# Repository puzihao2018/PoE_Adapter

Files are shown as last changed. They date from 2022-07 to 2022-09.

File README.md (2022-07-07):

# PoE_Adapter

## The Idea

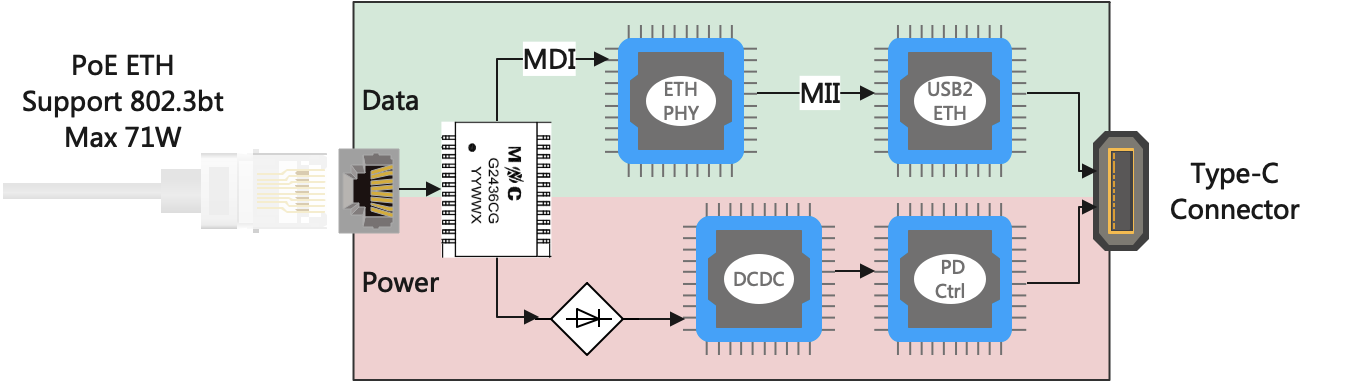
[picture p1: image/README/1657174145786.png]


## Requirements

* Support 802.3af, at, bt
* Maximum PoE input 71W
* Support 10M/100M/1G Ethernet, 2.5G or 10G better
* Support USB PD 60W(20V-3A) or higher, max to 65W
* Support USB PD 2.0 or higher, PPS support is better

## Related Knowledge

### About PoE

[什么是Power over Ethernet（PoE）? 它是如何工作的？ - 华为](https://info.support.huawei.com/info-finder/encyclopedia/zh/PoE.html)

[Power over Ethernet - Wikipedia](https://en.wikipedia.org/wiki/Power_over_Ethernet)

[](https://www.skyworksinc.com/-/media/Skyworks/SL/documents/public/white-papers/understanding-the-ieee-8023bt-poe-standard.pdf)

[【全系列】电源大咖课终极篇：EMC/功率隔离/PoE/LTspice_哔哩哔哩_bilibili](https://www.bilibili.com/video/BV1U54y167iA?p=6&vd_source=4a5614e8aaa017dad2b9a475db5972fe)

### About DCDC

### About USB2ETH

## Key Components

* [ ] 网口变压器
* [ ] PoE Interface IC
* [ ] ETH PHY Chip, MDI/MDIX to SGMII
* [ ] DCDC
* [ ] PD Control IC
* [ ] USB2ETH IC

## Possible Test Equipments

### PSE Devices

[HUAWEI ****AD-560161T0E POE++ Injector****](https://www.notion.so/HUAWEI-AD-560161T0E-POE-Injector-f2f963361bf641c6bf67e5bd52b6a7db)

[**Cudy POE400 90W Gigabit Ultra PoE++ Injector Adapter**](https://www.notion.so/Cudy-POE400-90W-Gigabit-Ultra-PoE-Injector-Adapter-ba70eb35d22a4e3bbaf1a9ec274cac1c)

[H3C S5130S-10MS-UPWR-EI Switch](https://www.notion.so/H3C-S5130S-10MS-UPWR-EI-Switch-632d7c23edca47faa28a7068c8aec5ac)

[QNAP ****QSW-M2116P-2T2S Switch****](https://www.notion.so/QNAP-QSW-M2116P-2T2S-Switch-efeddbc0777d48369dd353b2ddde7140)

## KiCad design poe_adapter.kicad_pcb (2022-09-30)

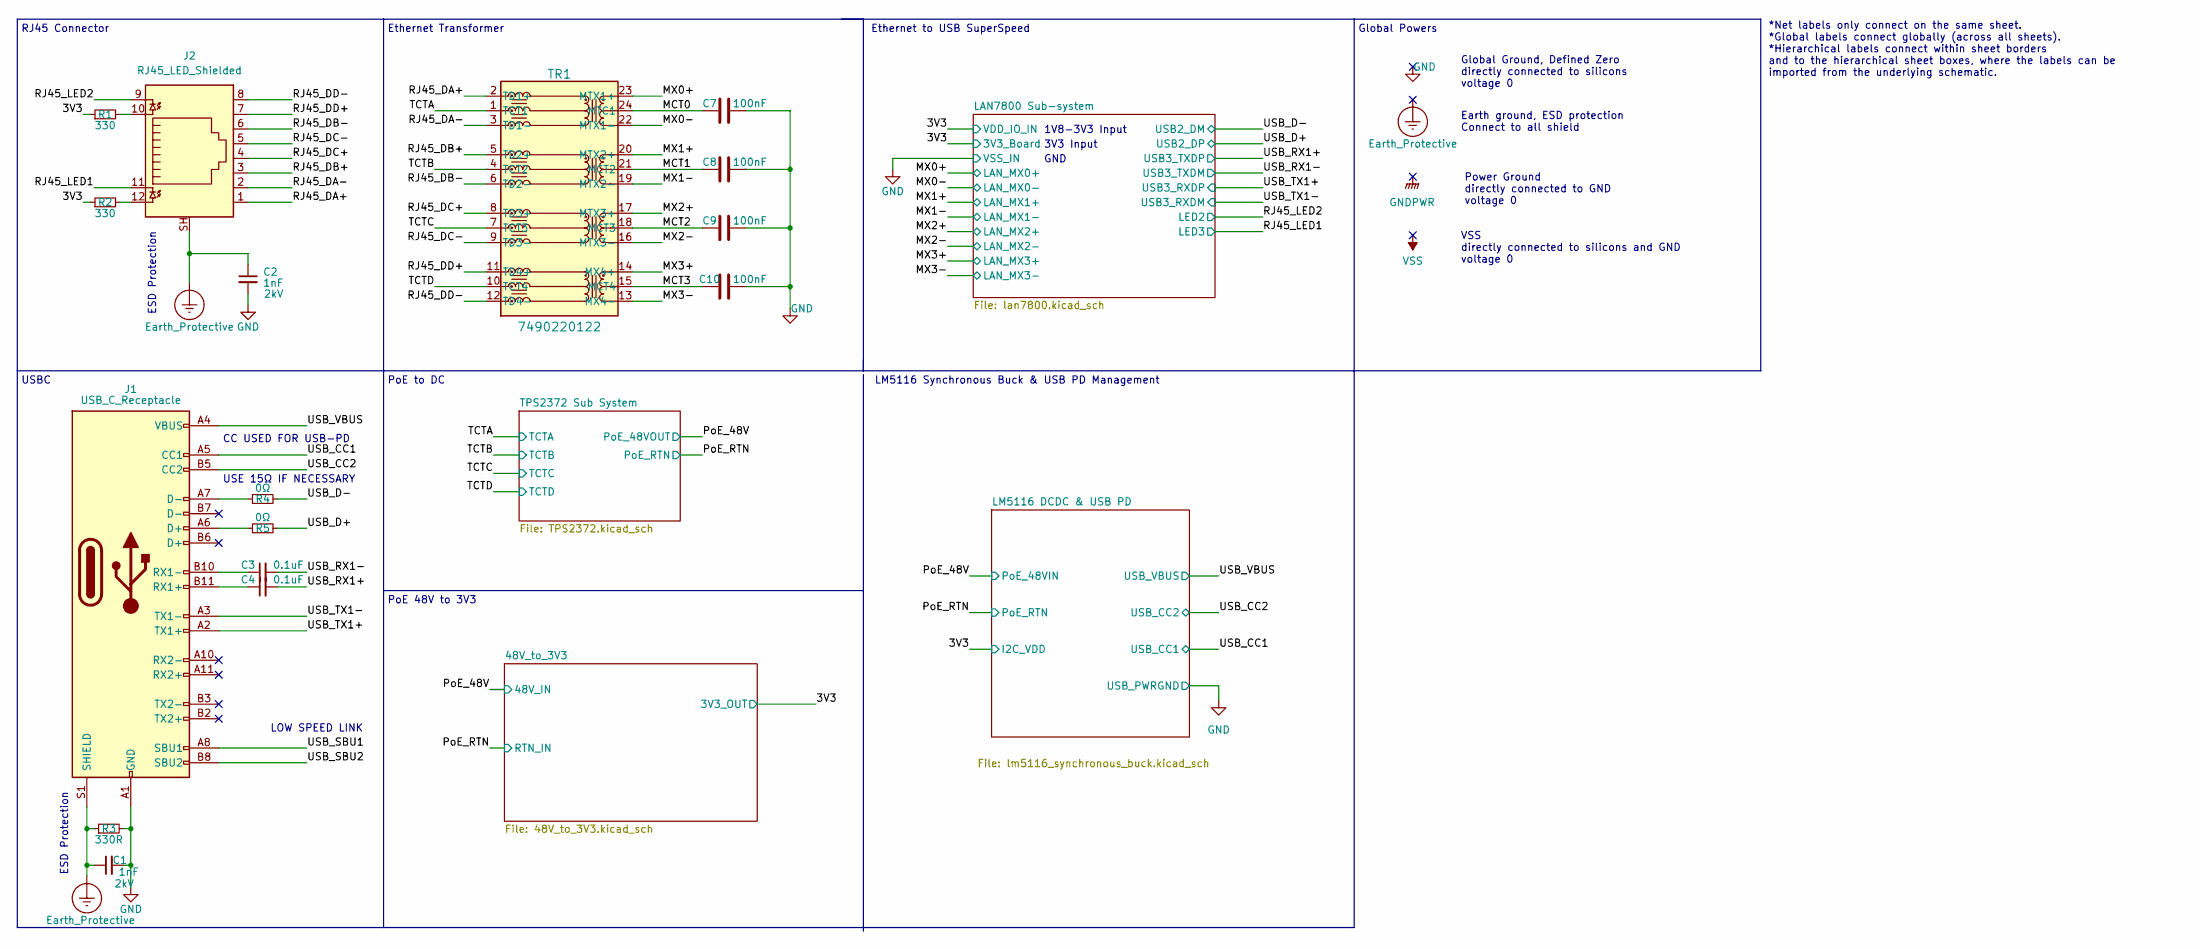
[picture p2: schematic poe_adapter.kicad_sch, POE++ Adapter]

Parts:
C1: 1nF; C_1206_3216Metric; Voltage 2kV
C2: 1nF; R_1206_3216Metric; Voltage 2kV
C3, C4: 0.1uF; C_0603_1608Metric
C7, C8, C9, C10: 100nF; C_1206_3216Metric
J1: USB_C_Receptacle; USB_C_Receptacle_Amphenol_12401610E4-2A_CircularHoles
J2: RJ45_LED_Shielded; RJ45_Amphenol_RJHSE538X
R1, R2: 330; R_0603_1608Metric
R3: 330R; R_0603_1608Metric
R4, R5: 0Ω; R_0603_1608Metric
TR1: 7490220122

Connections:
/MCT0: C7.2, TR1.24 (MTC1)
/MCT1: C8.2, TR1.21 (MCT2)
/MCT2: C9.2, TR1.18 (MCT3)
/MCT3: C10.2, TR1.15 (MCT4)
/MX0+: TR1.23 (MTX1+); also elsewhere on the board
/MX0-: TR1.22 (MTX1-); also elsewhere on the board
/MX1+: TR1.20 (MTX2+); also elsewhere on the board
/MX1-: TR1.19 (MTX2-); also elsewhere on the board
/MX2+: TR1.17 (MTX3+); also elsewhere on the board
/MX2-: TR1.16 (MTX3-); also elsewhere on the board
/MX3+: TR1.14 (MX4+); also elsewhere on the board
/MX3-: TR1.13 (MX4-); also elsewhere on the board
/RJ45_DA+: J2.1, TR1.2 (TD1+)
/RJ45_DA-: J2.2, TR1.3 (TD1-)
/RJ45_DB+: J2.3, TR1.5 (TD2+)
/RJ45_DB-: J2.6, TR1.6 (TD2-)
/RJ45_DC+: J2.4, TR1.8 (TD3+)
/RJ45_DC-: J2.5, TR1.9 (TD3-)
/RJ45_DD+: J2.7, TR1.11 (TD4+)
/RJ45_DD-: J2.8, TR1.12 (TD4-)
/RJ45_LED1: J2.11; also elsewhere on the board
/RJ45_LED2: J2.9; also elsewhere on the board
/TCTA: TR1.1 (TCT1); also elsewhere on the board
/TCTB: TR1.4 (TCT2); also elsewhere on the board
/TCTC: TR1.7 (TCT3); also elsewhere on the board
/TCTD: TR1.10 (TCT4); also elsewhere on the board
/USB_CC1: J1.A5 (CC1); also elsewhere on the board
/USB_CC2: J1.B5 (CC2); also elsewhere on the board
/USB_D+: R5.2; also elsewhere on the board
/USB_D-: R4.2; also elsewhere on the board
/USB_RX1+: C4.2; also elsewhere on the board
/USB_RX1-: C3.2; also elsewhere on the board
/USB_SBU1: J1.A8 (SBU1)
/USB_SBU2: J1.B8 (SBU2)
/USB_TX1+: J1.A2 (TX1+); also elsewhere on the board
/USB_TX1-: J1.A3 (TX1-); also elsewhere on the board
/USB_VBUS: J1.A4 (VBUS), J1.A9 (VBUS), J1.B4 (VBUS), J1.B9 (VBUS); also elsewhere on the board
Earth_Protective: C1.1, C2.1, J1.S1 (SHIELD), J2.SH, R3.1; also elsewhere on the board
unnamed: C3.1, J1.B10 (RX1-)
unnamed: C4.1, J1.B11 (RX1+)
unnamed: J1.A6 (D+), R5.1
unnamed: J1.A7 (D-), R4.1
unnamed: J2.10, R1.2
unnamed: J2.12, R2.2

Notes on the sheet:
USE 15Ω IF NECESSARY
RJ45 Connector
1V8-3V3 Input
Ethernet to USB SuperSpeed
Ethernet Transformer
PoE to DC
Earth ground, ESD protection Connect to all shield
Global Ground, Defined Zero directly connected to silicons voltage 0
USBC
GND
3V3 Input
CC USED FOR USB-PD
ESD Protection
LOW SPEED LINK
Power Ground directly connected to GND voltage 0
*Net labels only connect on the same sheet. *Global labels connect globally (across all sheets). *Hierarchical labels connect within sheet borders and to the hierarchical sheet boxes, where the labels can be imported from the underlying schematic.
VSS directly connected to silicons and GND voltage 0
PoE 48V to 3V3
LM5116 Synchronous Buck & USB PD Management
Global Powers

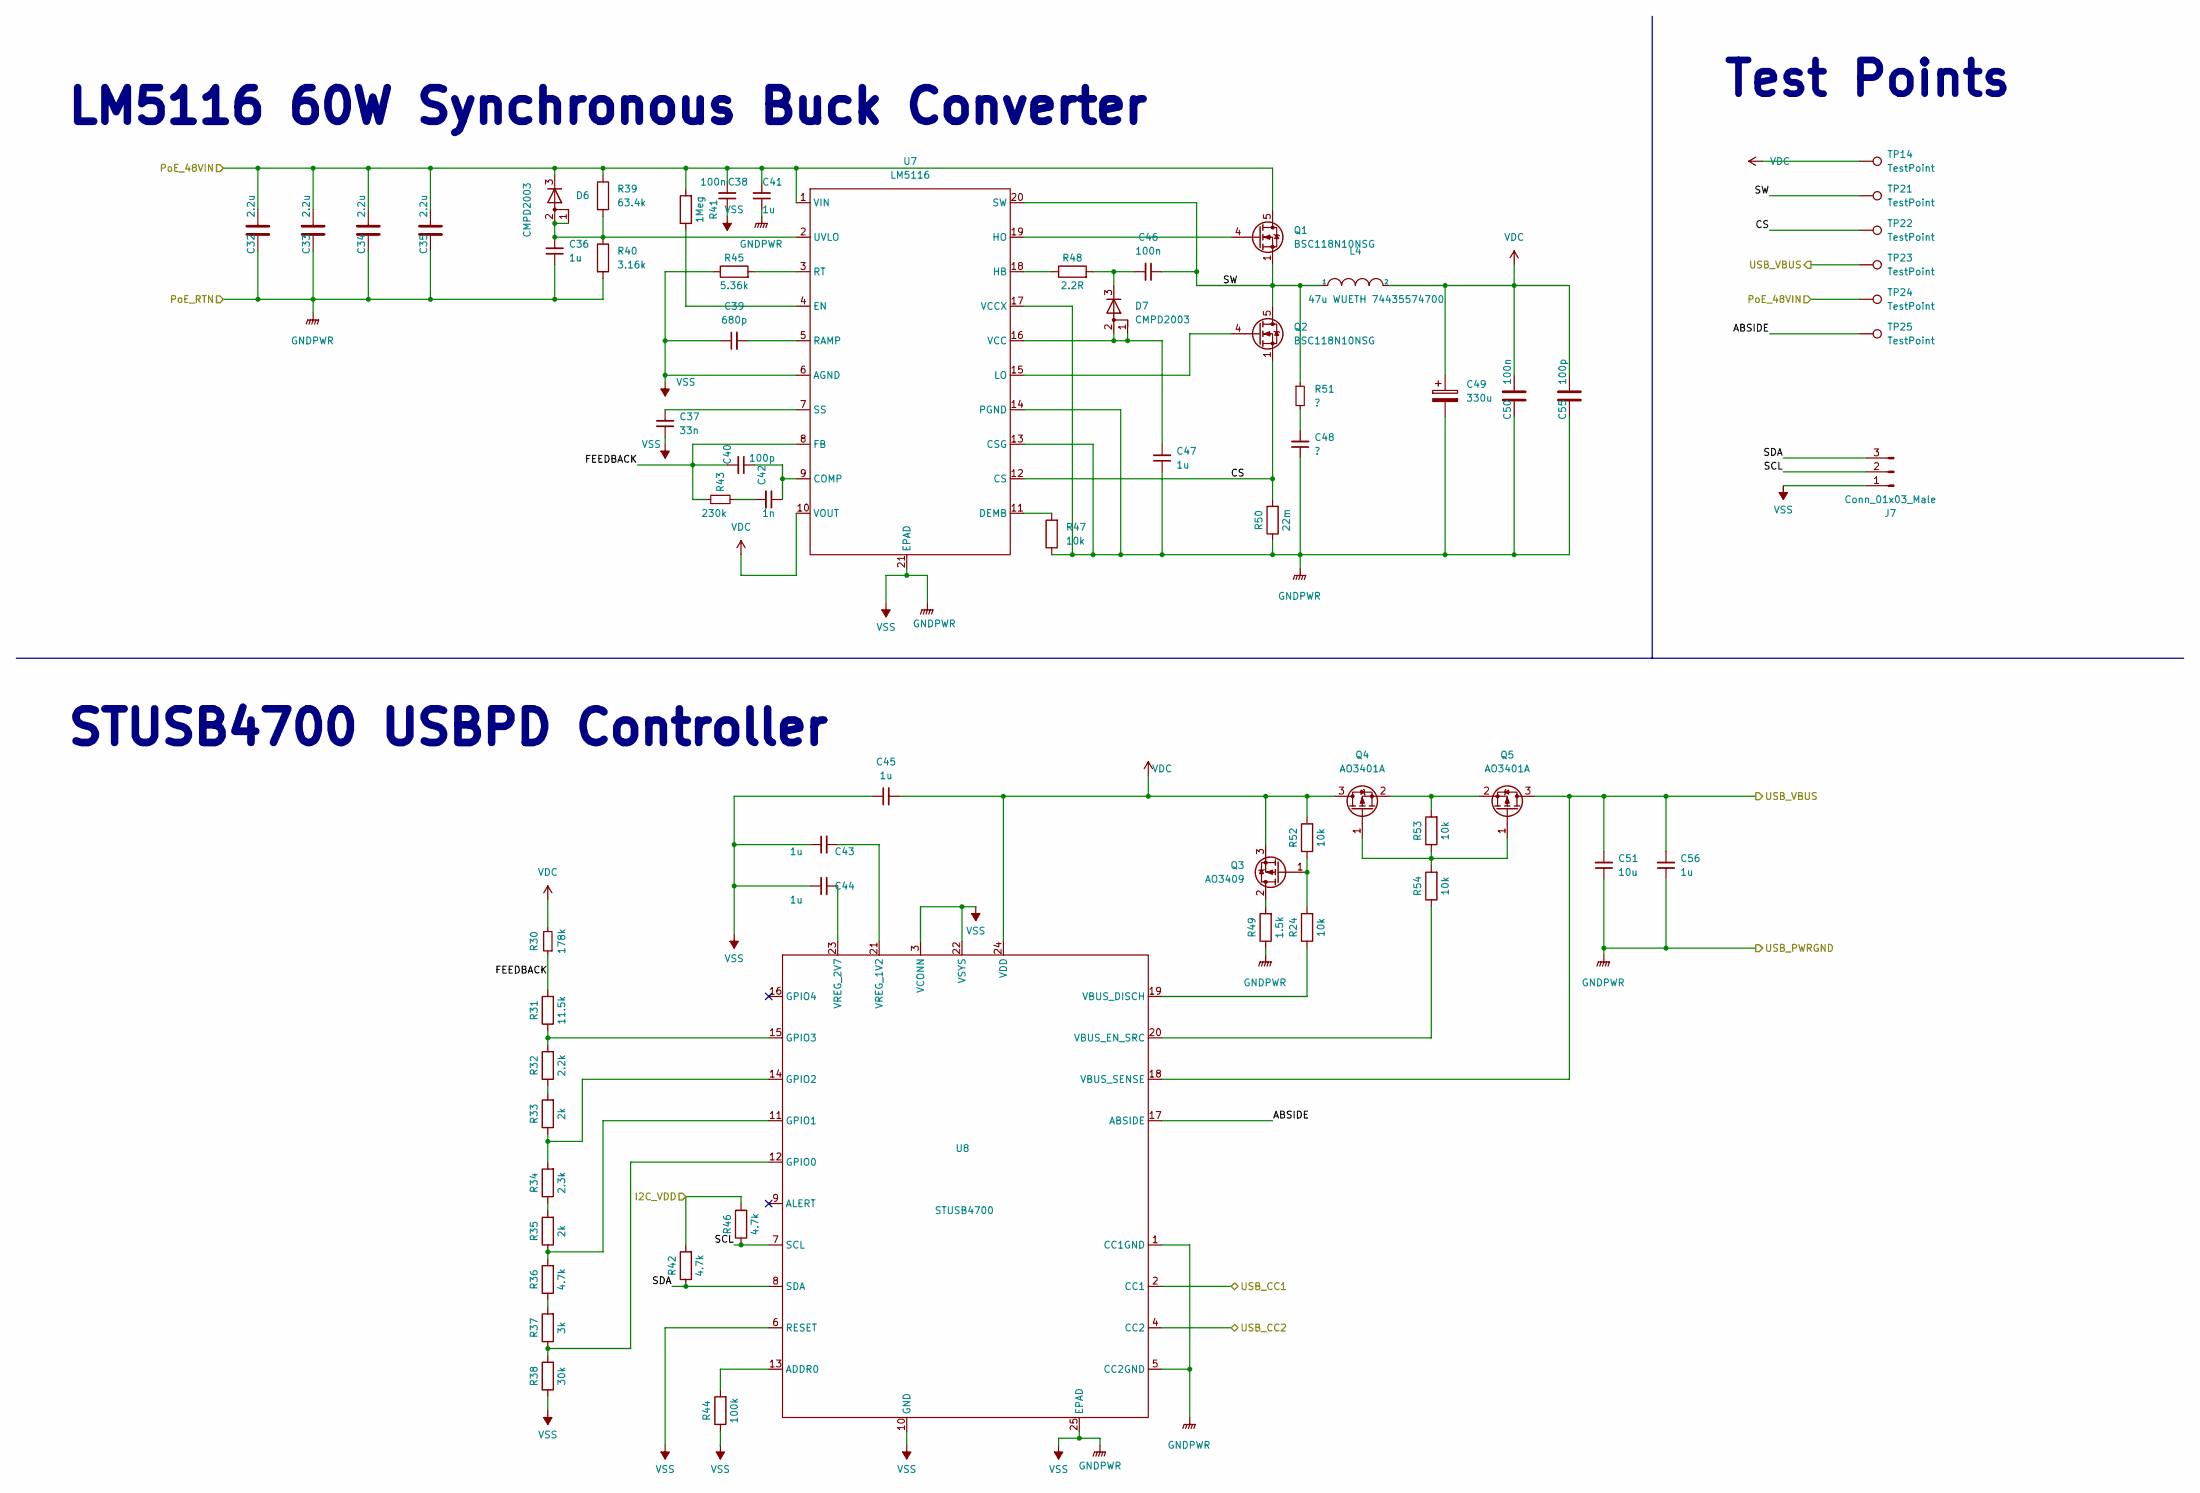
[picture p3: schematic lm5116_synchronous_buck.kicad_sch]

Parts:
C32, C33, C34, C35: 2.2u; C_0603_1608Metric
C36, C41, C43, C44, C45, C47, C56: 1u; C_0603_1608Metric
C37: 33n; C_0603_1608Metric
C38, C46, C50: 100n; C_0603_1608Metric
C39: 680p; C_0603_1608Metric
C40, C55: 100p; C_0603_1608Metric
C42: 1n; C_0603_1608Metric
C48: ?; C_0603_1608Metric
C49: 330u; C_Elec_10x10.2
C51: 10u; C_0805_2012Metric
D6, D7: CMPD2003; SOT-23
J7: Conn_01x03_Male; PinHeader_1x03_P1.00mm_Vertical
L4: 47u WUETH 74435574700; 74435574700
Q1, Q2: BSC118N10NSG; TDSON-8-1
Q3: AO3409; SOT-23
Q4, Q5: AO3401A; SOT-23
R24, R47, R52, R53, R54: 10k; R_0603_1608Metric
R30: 178k; R_0603_1608Metric
R31: 11.5k; R_0603_1608Metric
R32: 2.2k; R_0603_1608Metric
R33, R35: 2k; R_0603_1608Metric
R34: 2.3k; R_0603_1608Metric
R36, R42, R46: 4.7k; R_0603_1608Metric
R37: 3k; R_0603_1608Metric
R38: 30k; R_0603_1608Metric
R39: 63.4k; R_0603_1608Metric
R40: 3.16k; R_0603_1608Metric
R41: 1Meg; R_0603_1608Metric
R43: 230k; R_0603_1608Metric
R44: 100k; R_0603_1608Metric
R45: 5.36k; R_0603_1608Metric
R48: 2.2R; R_0805_2012Metric
R49: 1.5k; R_0603_1608Metric
R50: 22m; R_1206_3216Metric
R51: ?; R_0603_1608Metric
TP14, TP21, TP22, TP23, TP24, TP25: TestPoint; TestPoint_Pad_1.0x1.0mm
U7: LM5116; HTSSOP-20-1EP_4.4x6.5mm_P0.65mm_EP2.85x4mm
U8: STUSB4700; QFN-24-1EP_4x4mm_P0.5mm_EP2.7x2.7mm_ThermalVias

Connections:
/LM5116 DCDC & USB PD/ABSIDE: TP25.1, U8.17 (ABSIDE)
/LM5116 DCDC & USB PD/CS: Q2.1 (S), Q2.2 (S), Q2.3 (S), R50.2, TP22.1, U7.12 (CS)
/LM5116 DCDC & USB PD/FEEDBACK: C40.2, R30.1, R31.2, R43.1, U7.8 (FB)
/LM5116 DCDC & USB PD/SCL: J7.2, R46.1, U8.7 (SCL)
/LM5116 DCDC & USB PD/SDA: J7.3, R42.1, U8.8 (SDA)
/LM5116 DCDC & USB PD/SW: C46.1, L4.1, Q1.1 (S), Q1.2 (S), Q1.3 (S), Q2.5 (D), R51.1, TP21.1, U7.20 (SW)
/PoE_48V: C32.1, C33.1, C34.1, C35.1, C38.2, C41.2, D6.3 (K), Q1.5 (D), R39.1, R41.2, TP24.1, U7.1 (VIN); also elsewhere on the board
/USB_CC1: U8.2 (CC1); also elsewhere on the board
/USB_CC2: U8.4 (CC2); also elsewhere on the board
/USB_VBUS: C51.2, C56.2, Q5.3 (D), TP23.1, U8.18 (VBUS_SENSE); also elsewhere on the board
unnamed: C36.2, D6.1 (A), D6.2 (A), R39.2, R40.1, U7.2 (UVLO)
unnamed: C37.2, U7.7 (SS)
unnamed: C39.2, U7.5 (RAMP)
unnamed: C40.1, C42.1, U7.9 (COMP)
unnamed: C42.2, R43.2
unnamed: C43.2, U8.21 (VREG_1V2)
unnamed: C44.2, U8.23 (VREG_2V7)
unnamed: C46.2, D7.3 (K), R48.2
unnamed: C47.2, D7.1 (A), D7.2 (A), U7.16 (VCC)
unnamed: C48.2, R51.2
unnamed: Q1.4 (G), U7.19 (HO)
unnamed: Q2.4 (G), U7.15 (LO)
unnamed: Q3.1 (G), R24.2, R52.1
unnamed: Q3.2 (D), R49.2
unnamed: Q4.1 (G), Q5.1 (G), R53.1, R54.2
unnamed: Q4.2 (S), Q5.2 (S), R53.2
unnamed: R24.1, U8.19 (VBUS_DISCH)
unnamed: R31.1, R32.2, U8.15 (GPIO3)
unnamed: R32.1, R33.2
unnamed: R33.1, R34.2, U8.14 (GPIO2)
unnamed: R34.1, R35.2
unnamed: R35.1, R36.2, U8.11 (GPIO1)
unnamed: R36.1, R37.2
unnamed: R37.1, R38.2, U8.12 (GPIO0)
unnamed: R41.1, U7.4 (EN)
unnamed: R44.2, U8.13 (ADDR0)
unnamed: R45.2, U7.3 (RT)
unnamed: R47.2, U7.11 (DEMB)
unnamed: R48.1, U7.18 (HB)
unnamed: R54.1, U8.20 (VBUS_EN_SRC)
VDC: C45.2, C49.1, C50.1, C55.1, L4.2, Q3.3 (S), Q4.3 (D), R30.2, R52.2, TP14.1, U7.10 (VOUT), U8.24 (VDD)

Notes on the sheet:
STUSB4700 USBPD Controller
Test Points
LM5116 60W Synchronous Buck Converter

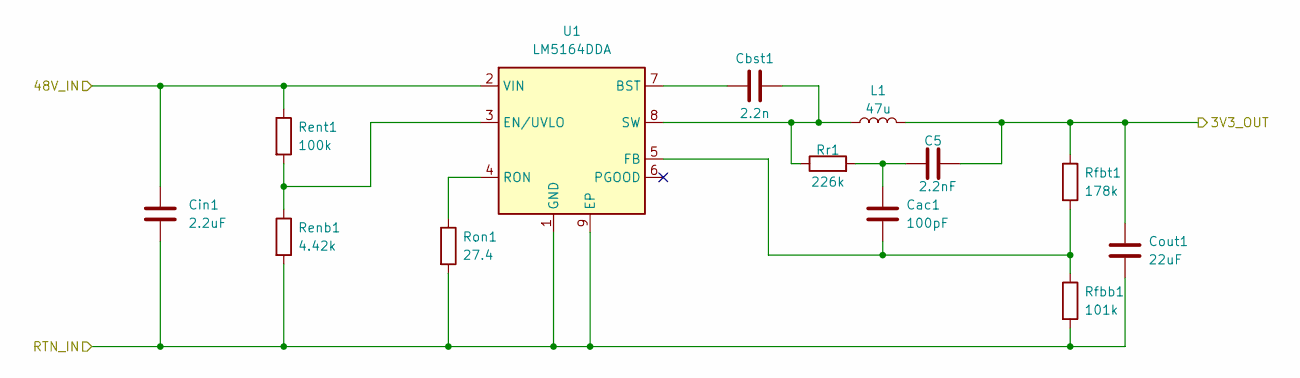
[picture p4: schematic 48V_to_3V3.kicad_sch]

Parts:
C5: 2.2nF; C_0603_1608Metric
Cac1: 100pF; C_0603_1608Metric
Cbst1: 2.2n; C_0603_1608Metric
Cin1: 2.2uF; C_1206_3216Metric
Cout1: 22uF; C_1206_3216Metric
L1: 47u; L_Wuerth_HCI-5040
Renb1: 4.42k; R_0603_1608Metric
Rent1: 100k; R_0603_1608Metric
Rfbb1: 101k; R_0603_1608Metric
Rfbt1: 178k; R_0603_1608Metric
Ron1: 27.4; R_0603_1608Metric
Rr1: 226k; R_0603_1608Metric
U1: LM5164DDA; HSOP-8-1EP_3.9x4.9mm_P1.27mm_EP2.41x3.1mm_ThermalVias

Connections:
/PoE_48V: C5.1, Cac1.2, Cin1.2, Cout1.1, Renb1.2, Rfbb1.2, Ron1.2, Rr1.2, U1.1 (VIN), U1.9 (EP); also elsewhere on the board
unnamed: Cbst1.1, U1.7 (BST)
unnamed 96: Ron1.1, U1.4 (FB); also elsewhere on the board

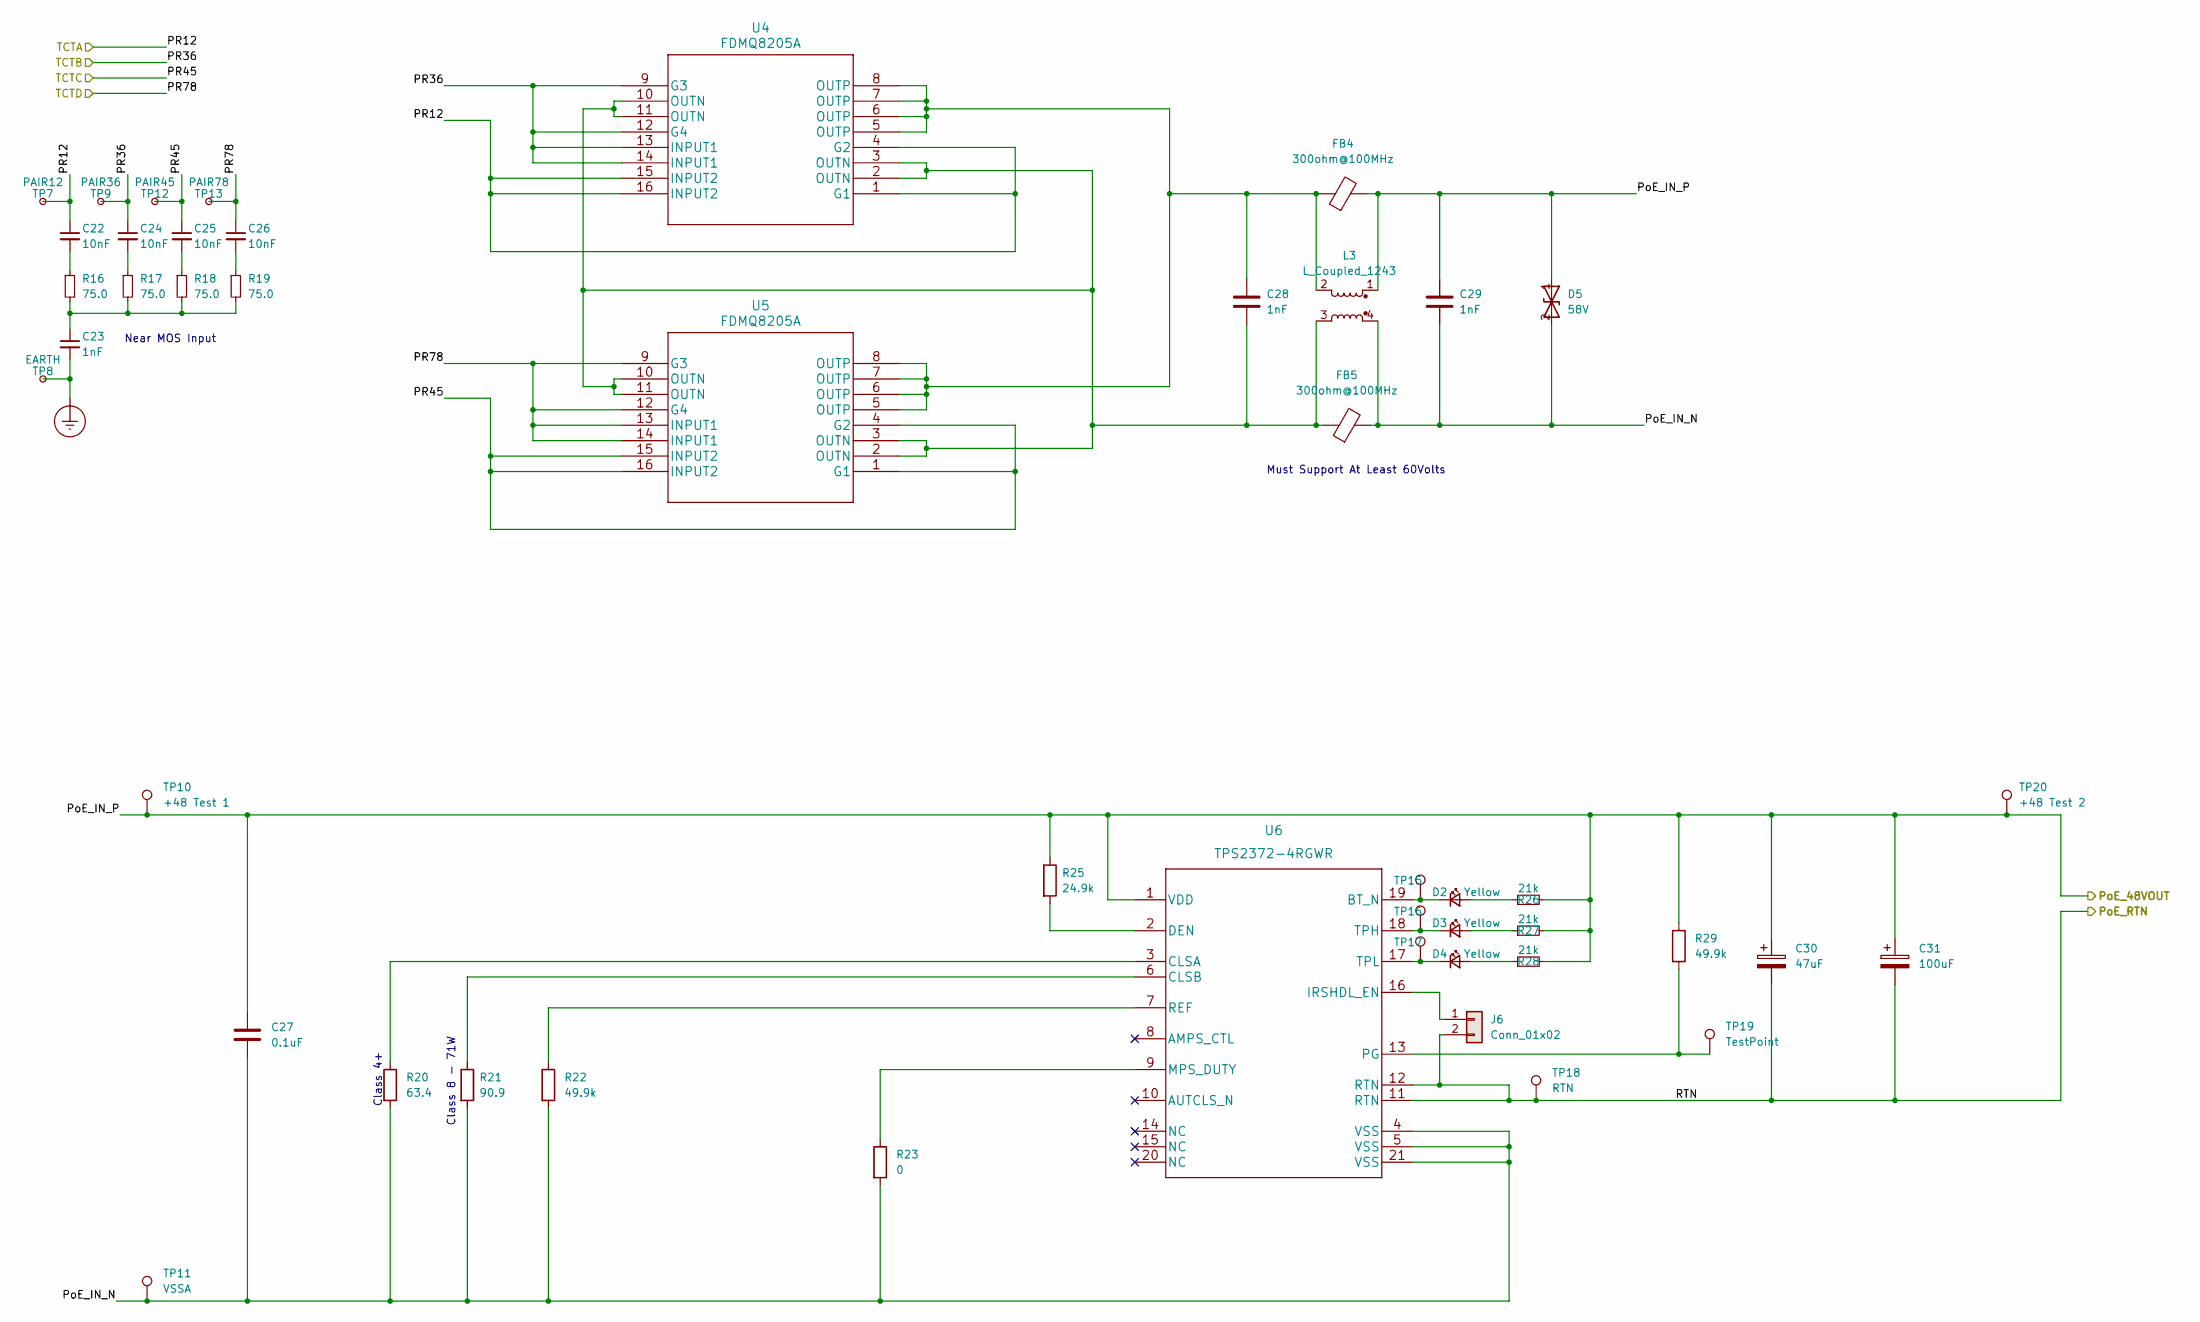
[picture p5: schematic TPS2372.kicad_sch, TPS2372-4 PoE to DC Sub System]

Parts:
C22, C24, C25, C26: 10nF; C_0603_1608Metric
C23, C28, C29: 1nF; C_0603_1608Metric
C27: 0.1uF; C_0805_2012Metric
C30: 47uF; EEV-TG2A470Q
C31: 100uF; CP_Elec_16x17.5
D2, D3, D4: Yellow; D_0603_1608Metric
D5: 58V; D_SMB
FB4, FB5: 300ohm@100MHz; L_0603_1608Metric
J6: Conn_01x02; PinHeader_1x02_P2.54mm_Vertical
L3: L_Coupled_1243; 744272251
R16, R17, R18, R19: 75.0; R_0603_1608Metric
R20: 63.4; R_0201_0603Metric
R21: 90.9; R_0603_1608Metric
R22, R29: 49.9k; R_0603_1608Metric
R23: 0; R_0603_1608Metric
R25: 24.9k; R_0603_1608Metric
R26, R27, R28: 21k; R_0603_1608Metric
TP7: PAIR12; TestPoint_Pad_1.0x1.0mm
TP8: EARTH; TestPoint_Pad_1.0x1.0mm
TP9: PAIR36; TestPoint_Pad_1.0x1.0mm
TP10: +48 Test 1; TestPoint_Pad_1.0x1.0mm
TP11: VSSA; TestPoint_Pad_1.0x1.0mm
TP12: PAIR45; TestPoint_Pad_1.0x1.0mm
TP13: PAIR78; TestPoint_Pad_1.0x1.0mm
TP15, TP16, TP17, TP19: TestPoint; TestPoint_Pad_1.0x1.0mm
TP18: RTN; TestPoint_Pad_1.0x1.0mm
TP20: +48 Test 2; TestPoint_Pad_1.0x1.0mm
U4, U5: FDMQ8205A
U6: TPS2372-4RGWR; TPS2372-3RGWR

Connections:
/PoE_48V: C27.1, C29.1, C30.1, C31.1, D5.1 (A1), FB4.2, L3.1, R25.1, R26.2, R27.2, R28.2, R29.1, TP10.1, TP20.1, U6.1 (VDD); also elsewhere on the board
/TCTA: C22.1, TP7.1, U4.1 (G1), U4.4 (G2), U4.15 (INPUT2), U4.16 (INPUT2); also elsewhere on the board
/TCTB: C24.1, TP9.1, U4.9 (G3), U4.12 (G4), U4.13 (INPUT1), U4.14 (INPUT1); also elsewhere on the board
/TCTC: C25.1, TP12.1, U5.1 (G1), U5.4 (G2), U5.15 (INPUT2), U5.16 (INPUT2); also elsewhere on the board
/TCTD: C26.1, TP13.1, U5.9 (G3), U5.12 (G4), U5.13 (INPUT1), U5.14 (INPUT1); also elsewhere on the board
/TPS2372 Sub System/PoE_IN_N: C27.2, C29.2, D5.2 (A2), FB5.2, L3.4, R20.2, R21.2, R22.2, R23.2, TP11.1, U6.4 (VSS), U6.5 (VSS), U6.21 (VSS)
Earth_Protective: C23.2, TP8.1; also elsewhere on the board
unnamed: C22.2, R16.1
unnamed: C23.1, R16.2, R17.2, R18.2, R19.2
unnamed: C24.2, R17.1
unnamed: C25.2, R18.1
unnamed: C26.2, R19.1
unnamed: C28.1, FB4.1, L3.2, U4.5 (OUTP), U4.6 (OUTP), U4.7 (OUTP), U4.8 (OUTP), U5.5 (OUTP), U5.6 (OUTP), U5.7 (OUTP), U5.8 (OUTP)
unnamed: C28.2, FB5.1, L3.3, U4.2 (OUTN), U4.3 (OUTN), U4.10 (OUTN), U4.11 (OUTN), U5.2 (OUTN), U5.3 (OUTN), U5.10 (OUTN), U5.11 (OUTN)
unnamed: D2.1 (K), TP15.1, U6.19 (BT_N)
unnamed: D2.2 (A), R26.1
unnamed: D3.1 (K), TP16.1, U6.18 (TPH)
unnamed: D3.2 (A), R27.1
unnamed: D4.1 (K), TP17.1, U6.17 (TPL)
unnamed: D4.2 (A), R28.1
unnamed: J6.1, U6.16 (IRSHDL_EN)
unnamed: R20.1, U6.3 (CLSA)
unnamed: R21.1, U6.6 (CLSB)
unnamed: R22.1, U6.7 (REF)
unnamed: R23.1, U6.9 (MPS_DUTY)
unnamed: R25.2, U6.2 (DEN)
unnamed: R29.2, TP19.1, U6.13 (PG)

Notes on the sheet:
Class 8 - 71W
Near MOS Input
Class 4+
Must Support At Least 60Volts

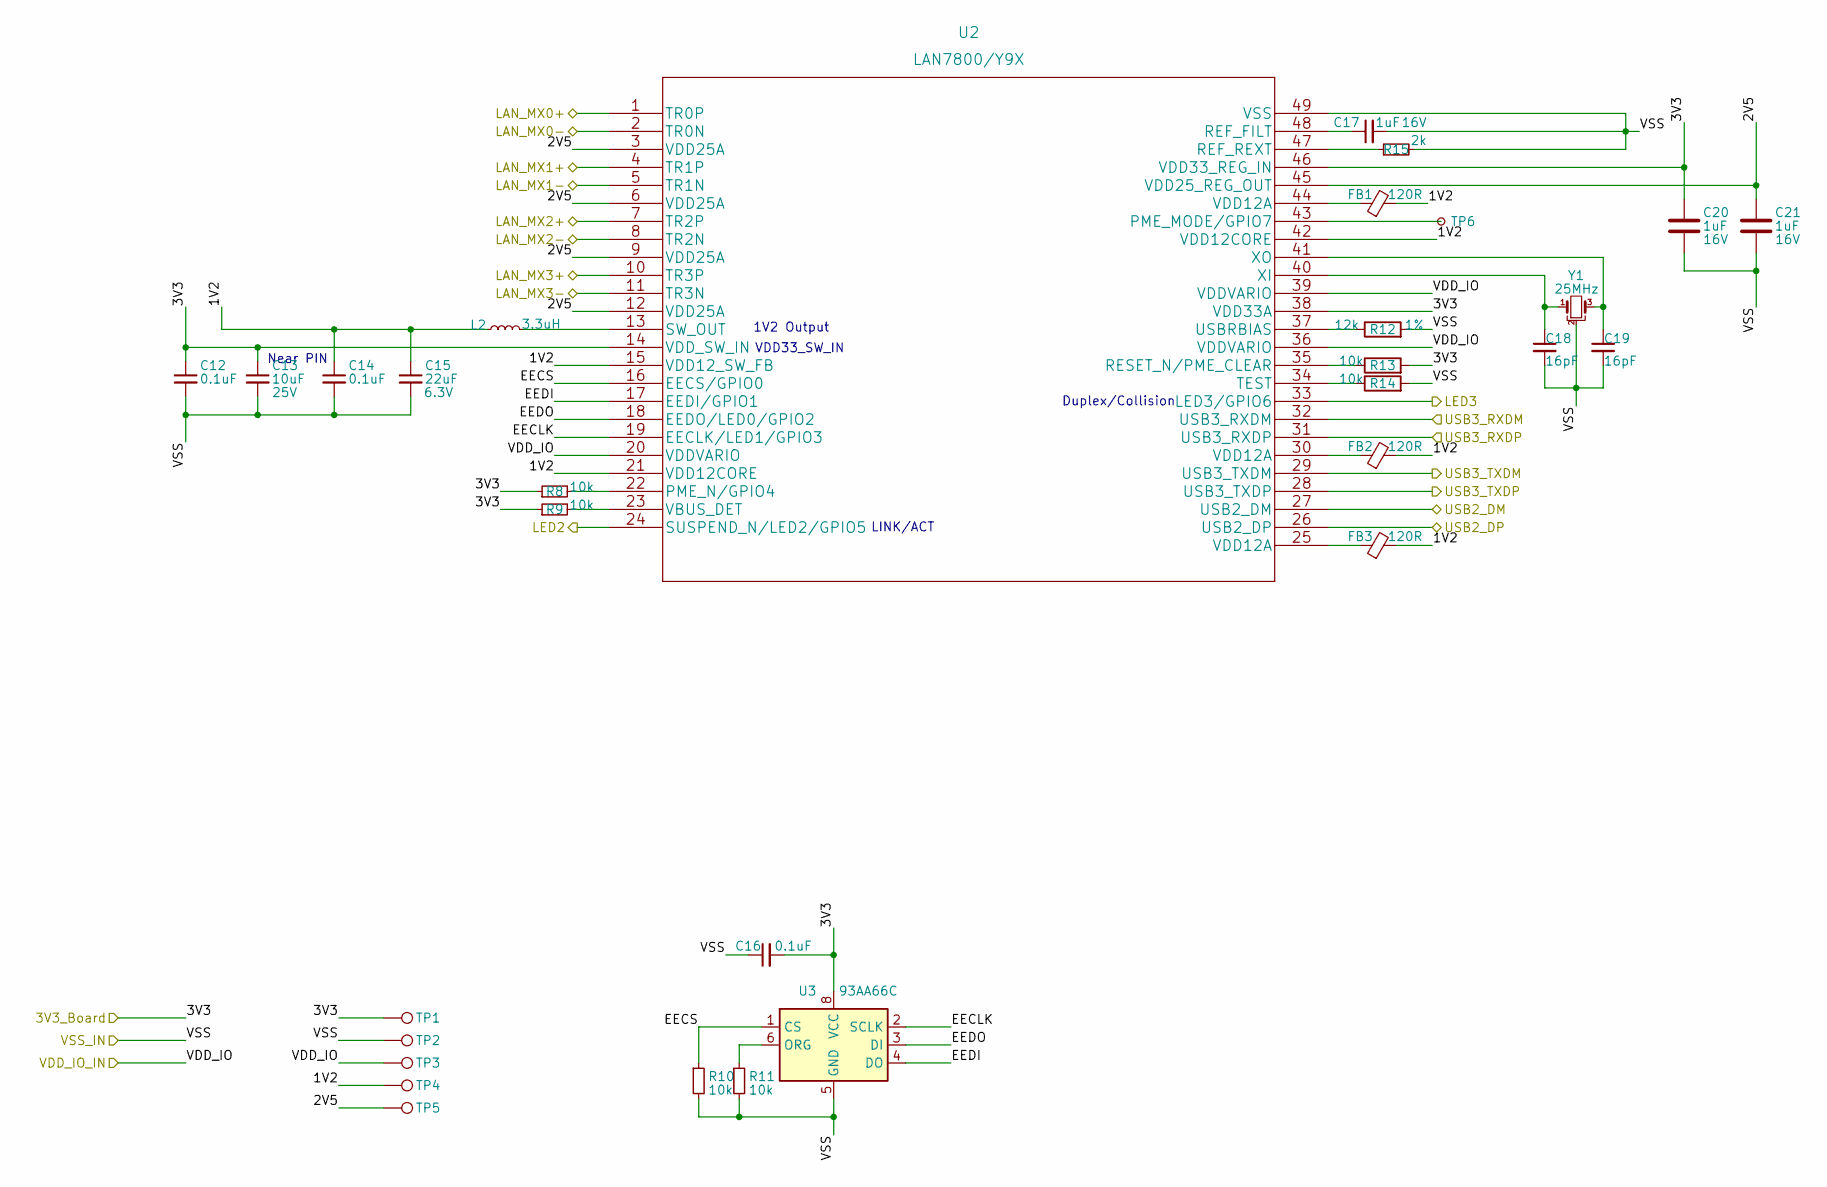
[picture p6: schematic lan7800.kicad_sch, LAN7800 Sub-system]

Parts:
C12, C14, C16: 0.1uF; C_0603_1608Metric
C13: 10uF; C_0603_1608Metric; Voltage 25V
C15: 22uF; C_0603_1608Metric; Voltage 6.3V
C17, C20, C21: 1uF; C_0603_1608Metric; Voltage 16V
C18, C19: 16pF; C_0603_1608Metric
FB1: 120R; L_0603_1608Metric
FB2, FB3: 120R; R_0603_1608Metric
L2: 3.3uH; L_1206_3216Metric
R8, R9, R10, R11, R13, R14: 10k; R_0603_1608Metric
R12: 12k; R_0603_1608Metric
R15: 2k; R_0603_1608Metric
TP1, TP2, TP3, TP4, TP5: TestPoint; TestPoint_Pad_1.0x1.0mm
TP6: TestPoint_Small; TestPoint_Pad_1.0x1.0mm
U2: LAN7800/Y9X; LAN7800&slash_Y9X
U3: 93AA66C; SOIC-8-1EP_3.9x4.9mm_P1.27mm_EP2.29x3mm
Y1: 25MHz; Crystal_SMD_3225-4Pin_3.2x2.5mm

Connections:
/LAN7800 Sub-system/1V2: C14.1, C15.1, FB1.2, FB2.2, FB3.2, L2.1, TP4.1, U2.15 (VDD12_SW_FB), U2.21 (VDD12CORE), U2.42 (VDD12CORE)
/LAN7800 Sub-system/2V5: C21.1, TP5.1, U2.3 (VDD25A), U2.6 (VDD25A), U2.9 (VDD25A), U2.12 (VDD25A), U2.45 (VDD25_REG_OUT)
/LAN7800 Sub-system/EECLK: U2.19 (EECLK/LED1/GPIO3), U3.2 (SCLK)
/LAN7800 Sub-system/EECS: R10.1, U2.16 (EECS/GPIO0), U3.1 (CS)
/LAN7800 Sub-system/EEDI: U2.17 (EEDI/GPIO1), U3.4 (DO)
/LAN7800 Sub-system/EEDO: U2.18 (EEDO/LED0/GPIO2), U3.3 (DI)
/MX0+: U2.1 (TR0P); also elsewhere on the board
/MX0-: U2.2 (TR0N); also elsewhere on the board
/MX1+: U2.4 (TR1P); also elsewhere on the board
/MX1-: U2.5 (TR1N); also elsewhere on the board
/MX2+: U2.7 (TR2P); also elsewhere on the board
/MX2-: U2.8 (TR2N); also elsewhere on the board
/MX3+: U2.10 (TR3P); also elsewhere on the board
/MX3-: U2.11 (TR3N); also elsewhere on the board
/RJ45_LED1: U2.33 (LED3/GPIO6); also elsewhere on the board
/RJ45_LED2: U2.24 (SUSPEND_N/LED2/GPIO5); also elsewhere on the board
/USB_D+: U2.26 (USB2_DP); also elsewhere on the board
/USB_D-: U2.27 (USB2_DM); also elsewhere on the board
/USB_RX1+: U2.28 (USB3_TXDP); also elsewhere on the board
/USB_RX1-: U2.29 (USB3_TXDM); also elsewhere on the board
/USB_TX1+: U2.31 (USB3_RXDP); also elsewhere on the board
/USB_TX1-: U2.32 (USB3_RXDM); also elsewhere on the board
unnamed: C17.1, U2.48 (REF_FILT)
unnamed: C18.1, U2.40 (XI), Y1.1
unnamed: C19.1, U2.41 (XO), Y1.3
unnamed: FB1.1, U2.44 (VDD12A)
unnamed: FB2.1, U2.30 (VDD12A)
unnamed: FB3.1, U2.25 (VDD12A)
unnamed: L2.2, U2.13 (SW_OUT)
unnamed: R8.2, U2.22 (PME_N/GPIO4)
unnamed: R9.2, U2.23 (VBUS_DET)
unnamed: R11.1, U3.6 (ORG)
unnamed: R12.1, U2.37 (USBRBIAS)
unnamed: R13.1, U2.35 (RESET_N/PME_CLEAR)
unnamed: R14.1, U2.34 (TEST)
unnamed: R15.1, U2.47 (REF_REXT)
unnamed: TP6.1, U2.43 (PME_MODE/GPIO7)

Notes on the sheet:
LINK/ACT
VDD33_SW_IN
1V2 Output
Duplex/Collision
Near PIN

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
Board: 4 copper layers, 170 parts (0 on the bottom side), 126 nets, no tracks yet.

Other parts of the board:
C6, C52, C53: 4.7uF; C_1206_3216Metric
C11: 330uF; CP_Elec_8x10
C54: 100uF; CP_Elec_10x10
D1: 60V 1A; D_SMA
R6: 3.4k; R_0603_1608Metric
R7: 2k; R_0603_1608Metric

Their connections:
/PoE_48V: C6.1, C52.1, C53.1, C54.1; also elsewhere on the board
unnamed 96: R6.2, R7.1; also elsewhere on the board

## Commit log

2022-07-07 repo init with readme
    [poe_adapter.kicad_pcb, poe_adapter.kicad_sch]
2022-07-07 LAN7800 Update 220707
    [lan7800.kicad_sch, poe_adapter.kicad_sch]
2022-07-07 LAN7800 Update 220707-2
    [poe_adapter.kicad_sch]
2022-07-10 LAN7800 update 0710
    [lan7800.kicad_sch, poe_adapter.kicad_sch]
2022-07-12 Added initial annotated DCDC ic components and power stage design caculations
    [UCC2897A USB PD Forward Converter Annotated Deisgn Sheet.xlsx]
2022-07-12 finish datalink
    [lan7800.kicad_sch, poe_adapter.kicad_sch]
2022-07-12 led update
    [poe_adapter.kicad_sch]
2022-07-13 *updated power converter design calculations
    *added initial TINA simulation file
    [UCC2897A USB PD Forward Converter Annotated Deisgn Sheet.xlsx]
2022-07-14 change 20220714, update datalink
    [lan7800.kicad_sch, poe_adapter.kicad_sch]
2022-07-18 tps2372 init
    [TPS2372.kicad_sch, poe_adapter.kicad_sch]
2022-07-26 tps2372 finish
    [PoE_Adapter.xlsx, TPS2372.kicad_sch, poe_adapter.kicad_sch]
2022-07-28 buck converter init
    [TPS2372.kicad_sch, lm5116_synchronous_buck.kicad_sch, poe_adapter.kicad_sch]
2022-07-28 TPS2372 Modified, test jumpers removed
    [TPS2372.kicad_sch, poe_adapter.kicad_sch]
2022-07-29 PoE TR change to 7490220122; updated pwr net
    [TPS2372.kicad_sch, lan7800.kicad_sch, poe_adapter.kicad_sch]
2022-07-30 LM2575 added, provide 3V3
    [TPS2372.kicad_sch, poe_adapter.kicad_sch]
2022-07-30 * put lm5116 symbol to its own folder
    * added stusb4700 symbol
    * finished DCDC converter schema
    [lm5116_synchronous_buck.kicad_sch, poe_adapter.kicad_sch]
2022-07-31 finished schema of lm5116 and USB4700
    [lm5116_synchronous_buck.kicad_sch, poe_adapter.kicad_sch]
2022-08-01 added 3v3 for scl & sda pins on stusb4700
    [lm5116_synchronous_buck.kicad_sch, poe_adapter.kicad_sch]
2022-08-02 power symbol updated
    [lan7800.kicad_sch, poe_adapter.kicad_sch]
2022-09-12 finished lm5116 circuit foot print assignment
    [TPS2372.kicad_sch, lan7800.kicad_sch, lm5116_synchronous_buck.kicad_sch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]
2022-09-18 PoE Library Update
    [lan7800.kicad_sch, poe_adapter.kicad_sch]
2022-09-18 footprint for power inductor and cap
    [lm5116_synchronous_buck.kicad_sch, poe_adapter.kicad_sch]
2022-09-19 footprint update
    [lm5116_synchronous_buck.kicad_sch, poe_adapter.kicad_sch]
2022-09-19 changed CC pin tags
    [lm5116_synchronous_buck.kicad_sch, poe_adapter.kicad_sch]
2022-09-20 Footprint without TPS2372
    [lan7800.kicad_sch, poe_adapter.kicad_sch]
2022-09-21 Footprint done
    [TPS2372.kicad_sch, poe_adapter.kicad_sch]
2022-09-25 ERC Check Finish
    [lm5116_synchronous_buck.kicad_sch, poe_adapter.kicad_sch]
2022-09-25 Update PCB
    [TPS2372.kicad_sch, lan7800.kicad_sch, lm5116_synchronous_buck.kicad_sch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]
2022-09-25 PCB Design Rule updated
    [poe_adapter.kicad_pcb, poe_adapter.kicad_sch]
2022-09-25 Layout Update
    [poe_adapter.kicad_pcb]
2022-09-25 crude layout
    [poe_adapter.kicad_pcb]
2022-09-26 Update 3V3 Solution
    [48V_to_3V3.kicad_sch, poe_adapter.kicad_sch]
2022-09-30 layout power stage
    [poe_adapter.kicad_pcb]

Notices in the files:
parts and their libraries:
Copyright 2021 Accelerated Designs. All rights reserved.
